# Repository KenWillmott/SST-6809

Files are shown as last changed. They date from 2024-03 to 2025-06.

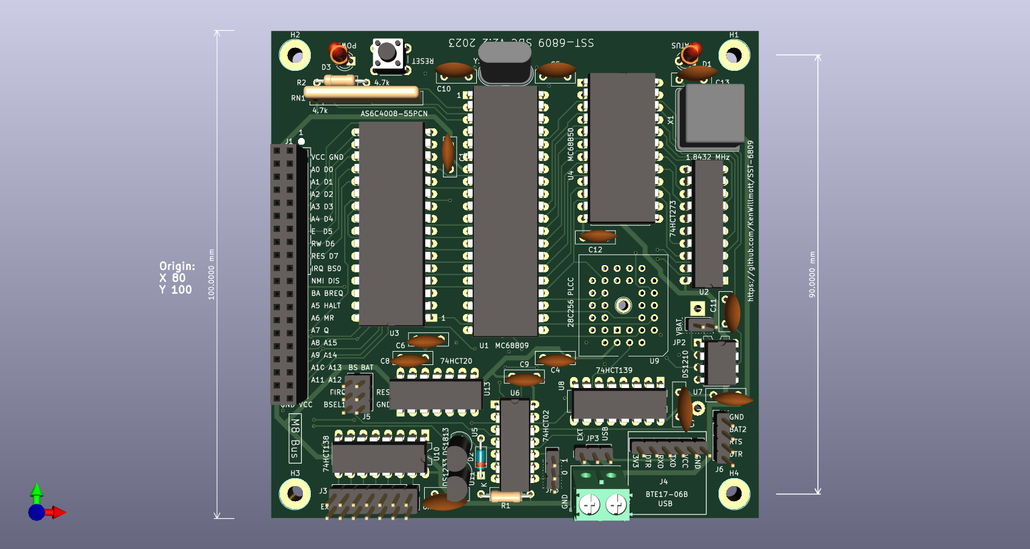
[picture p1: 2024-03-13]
stplus.png

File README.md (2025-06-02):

# SST-6809
MC6809 Single Board Computer

stplus

The SST is a stand alone MC6809 computer. It is inspired by the simple MC6809 SBC designed by Grant Searle:
http://searle.x10host.com/6809/Simple6809.html
and committed to a PCB design by Jeff Tranter:
http://jefftranter.blogspot.com/2019/01/a-6809-single-board-computer.html

It can be seen that what I call the Searle-Tranter design, has the following features:
- minimal ICs employed to make a useful stand alone system
- no PAL, GAL, or other programmable support logic ("glue") IC's, instead only standard 74xx MSI logic parts
- entirely through hole, DIP IC construction consistent with a vintage design. No surface mount components at all

The SST-6809 maintains the same overall approach, while adding some improvements and enhancements. Thus it is a "Super Searle Tranter" or SST. The fundamental features are:
- fairly granular address decoding, using only 4 74xx devices and one address latch for expanded memory
- full featured expansion bus, several expansion boards are already available
- separate UART and CPU clocks, allowing the MCU to run at the maximum 2.0MHz with the same 115200 baud communications
- 512kb NVRAM provides 56kb main and 456kb random access, battery backed up storage
- 32kb EEPROM jumper and software selectable in 4kb pages.
- option to use either USB adapter power, or 5V provided at screw connector terminals

The 10cm x 10cm form factor, including standard connector and mounting locations, create a "family" of boards that can interoperate in different ways. As a very minimal board, the SST does not support all of them, however its connector will support up to about 3 standard peripheral card in the M8 family, such as the M8 game board or the M8 6522/proto board. This can be accomplished using stacking connectors. The same boards may be used as vertically mounted cards on a bus - this configuration is a work in progress, however all the current cards could be used in that configuration instead (with a different connector installed).

The first PCB (V1.0) status was "assembled and testing". The EEPROM fails, a problem with the pin assignments was found.

The second and third PCB, V2.0 and V2.1, were completed. These intermediate versions do work, but V2.0 requires wire jumpers to replace a missing trace.

The current board version, V2.2, is fully operational and has some improvements such as selectable I/O memory address, and socket compatibility of 128/512k NVRAM IC's.

Detailed information can be found at:
https://exileinparadise.com/sst-6809:top
as well as the wiki:
https://github.com/KenWillmott/SST-6809/wiki

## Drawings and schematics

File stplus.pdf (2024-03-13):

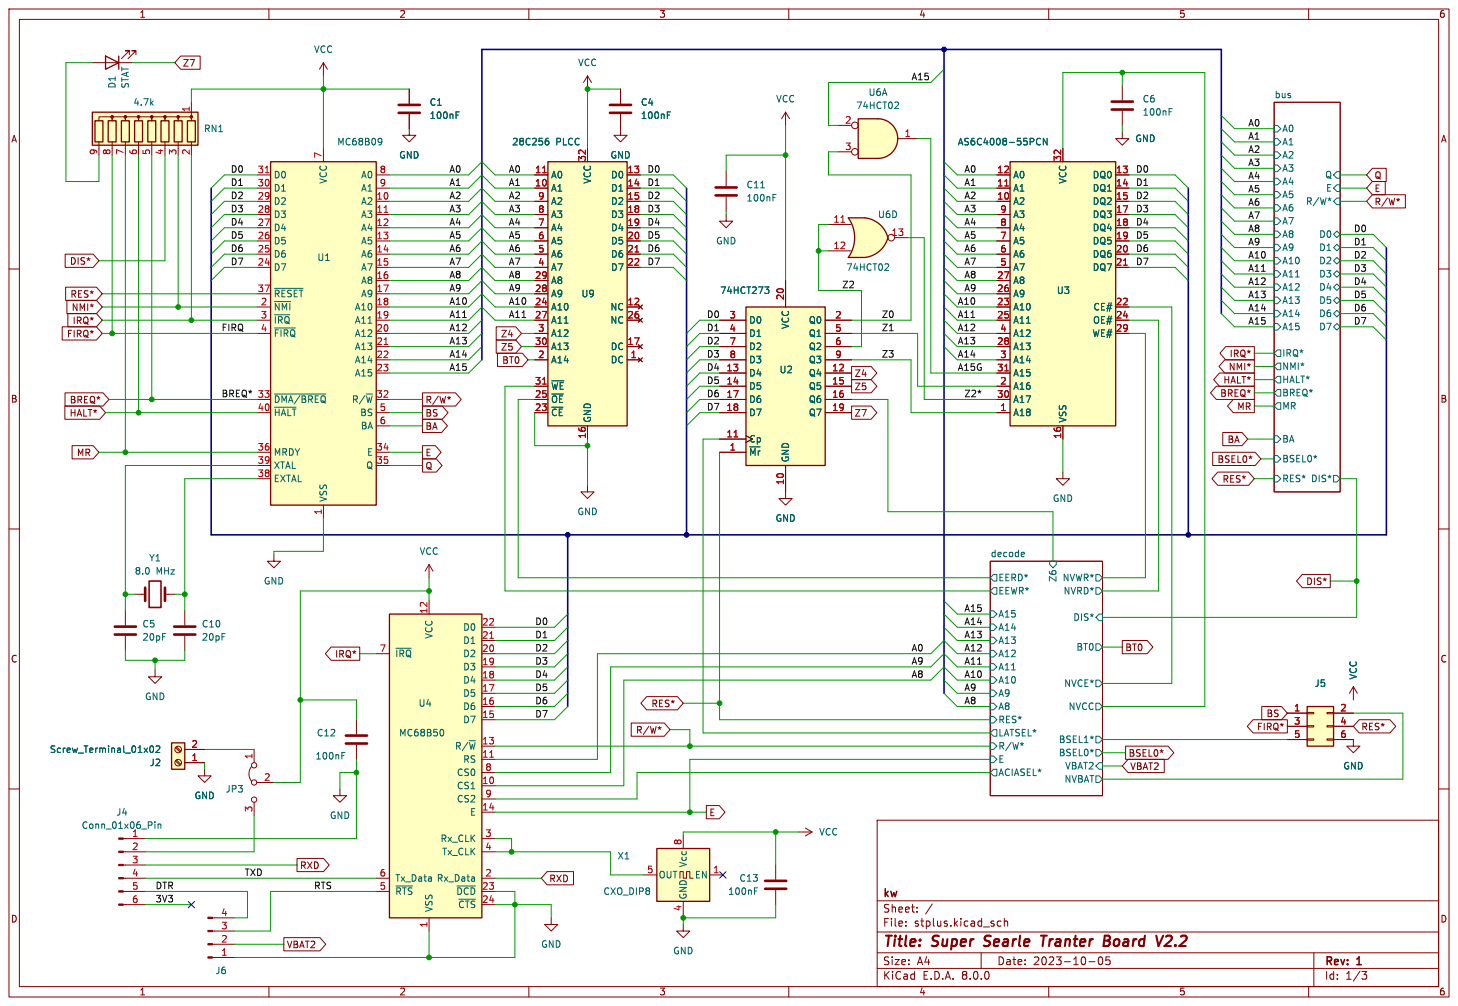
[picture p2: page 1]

1 A2 10 A3 11 A4 12 A5 13 A6 14 A7 15 A8 16 A9 17 A10 18 A11 19 ~{NMI} 2 A12 20 A13 21 A14 22 A15 23 D7 24 D6 25 D5 26 D4 27 D3 28 D2 29 ~{IRQ} 3 D1 30 D0 31 R/~{W}32 ~{DMA/BREQ} 33 E

File: stplus.kicad_sch Sheet: / kw

Id: 1/3 Title: Super Searle Tranter Board V2.2

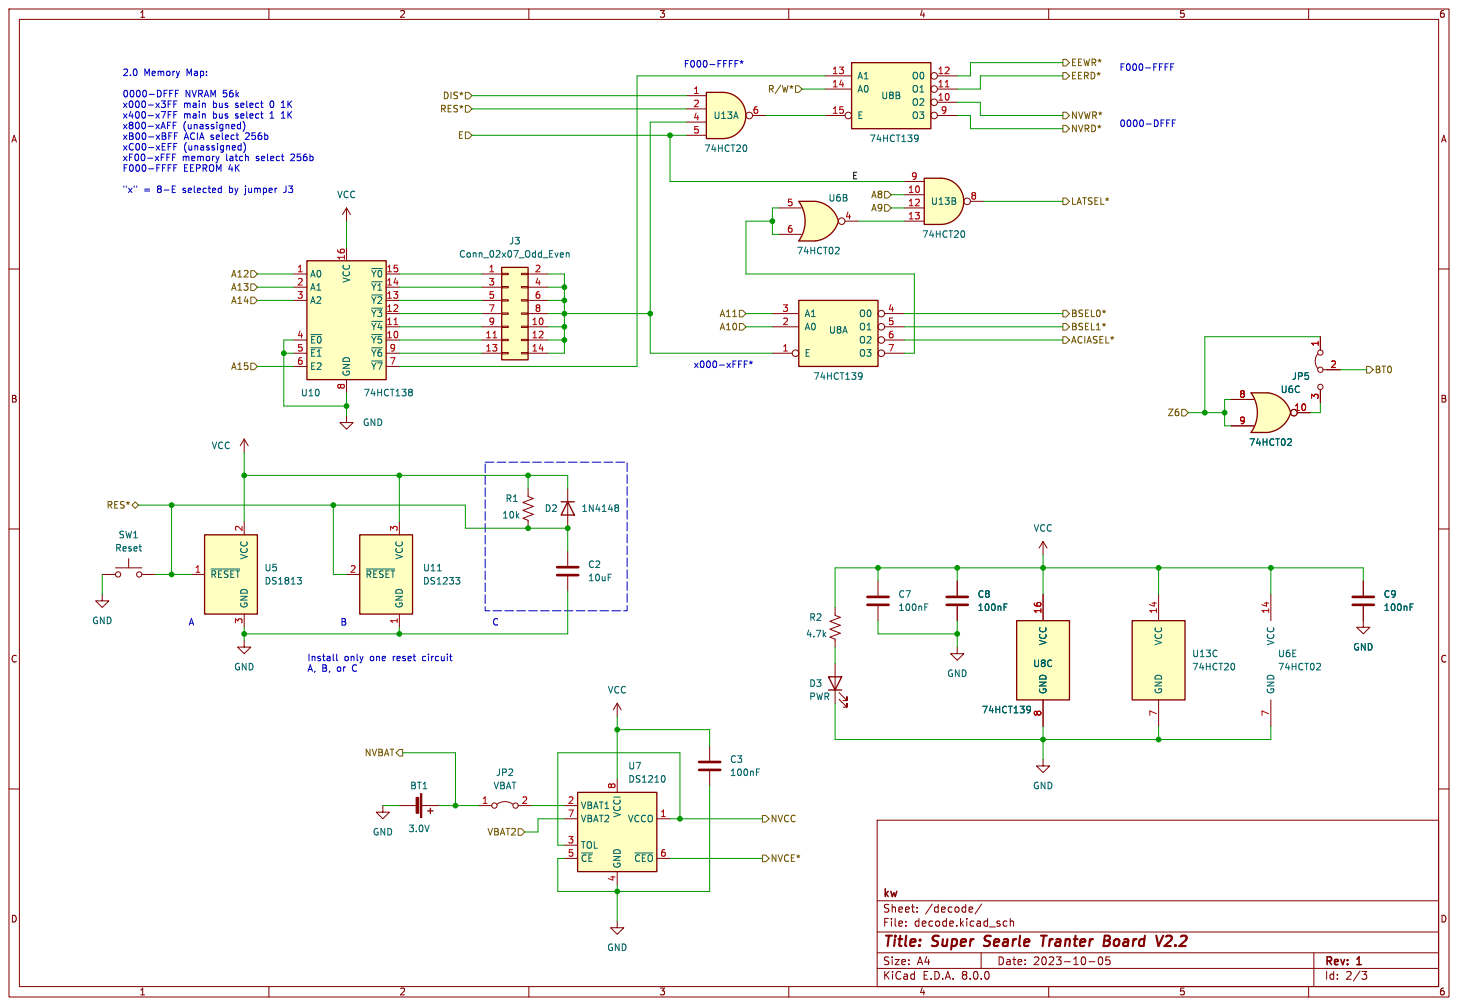
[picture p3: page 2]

LATSEL* EEWR* EERD* NVWR* NVRD* BSEL0* ACIASEL* E

File: decode.kicad_sch Sheet: /decode/ kw

Id: 2/3 Title: Super Searle Tranter Board V2.2

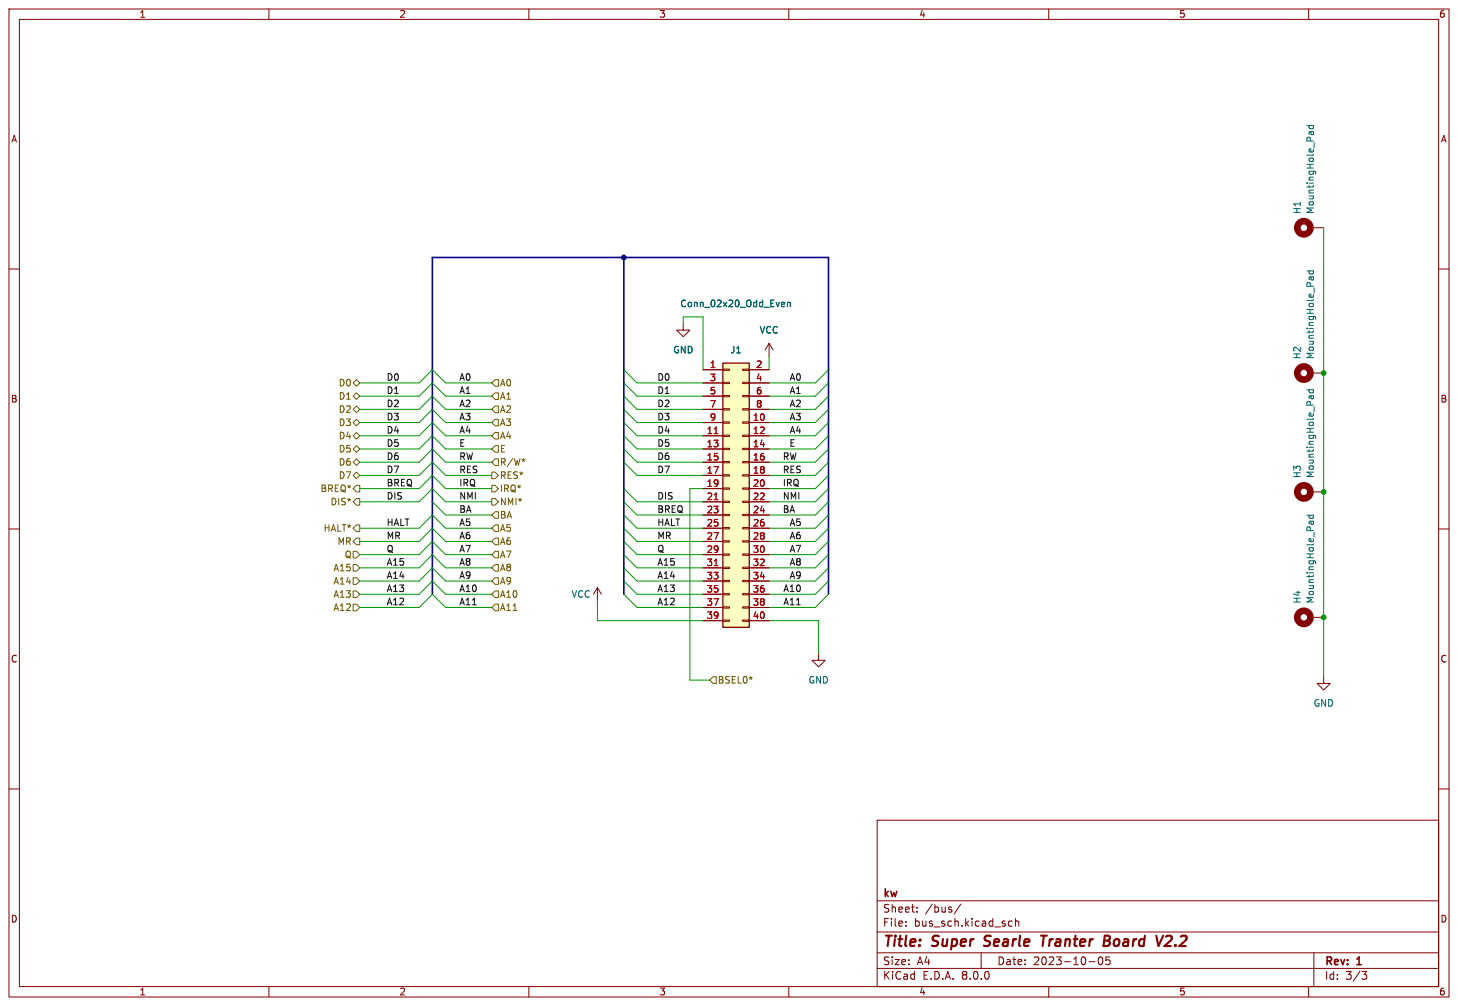
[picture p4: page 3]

File: bus_sch.kicad_sch Sheet: /bus/ kw 1

Id: 3/3 Title: Super Searle Tranter Board V2.2

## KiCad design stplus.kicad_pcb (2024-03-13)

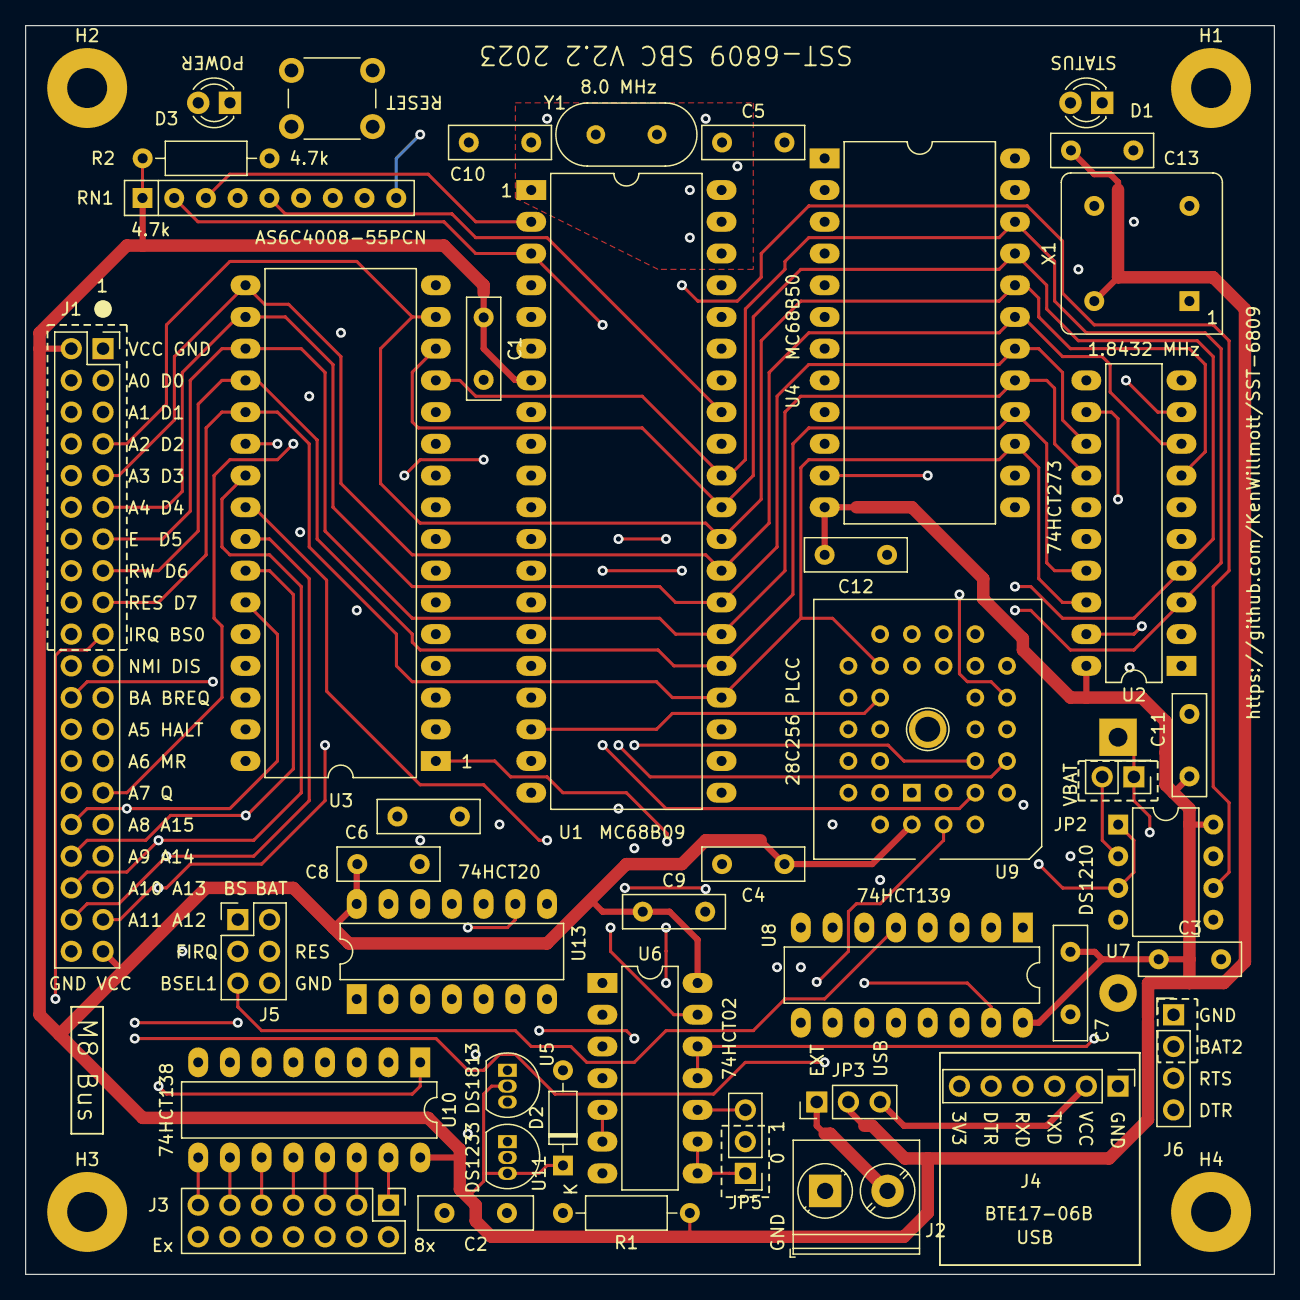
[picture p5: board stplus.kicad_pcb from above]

Board: 4 copper layers, 100.0 x 100.0 mm, 48 parts (1 on the bottom side), 87 nets.

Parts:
BT1: 3.0V; BatteryHolder_Keystone_103_1x20mm
C1, C3, C4, C6, C8, C9, C11, C12, C13: 100nF; C_Disc_D8.0mm_W2.5mm_P5.00mm
C2: 10uF; C_Disc_D9.0mm_W2.5mm_P5.00mm
C5, C10: 20pF; C_Disc_D8.0mm_W2.5mm_P5.00mm
C7: 100nF; C_Disc_D9.0mm_W2.5mm_P5.00mm
D1: STAT; LED_D3.0mm
D2: 1N4148; D_DO-35_SOD27_P7.62mm_Horizontal
D3: PWR; LED_D3.0mm
H1, H2, H3, H4: MountingHole_Pad; MountingHole_3.2mm_M3_Pad
J1: Conn_02x20_Odd_Even; PinSocket_2x20_P2.54mm_Vertical
J2: Screw_Terminal_01x02; TerminalBlock_Phoenix_PT-1,5-2-5.0-H_1x02_P5.00mm_Horizontal
J3: Conn_02x07_Odd_Even; PinHeader_2x07_P2.54mm_Vertical
J4: Conn_01x06_Pin; PinHeader_1x06_P2.54mm_Vertical
J5: Conn_02x03_Odd_Even; PinHeader_2x03_P2.54mm_Vertical
J6: Conn_01x04_Pin; PinHeader_1x04_P2.54mm_Vertical
JP2: VBAT; PinHeader_2x01_P2.54mm_Vertical
JP3, JP5: Jumper_3_Bridged12; PinHeader_1x03_P2.54mm_Vertical
R1: 10k; R_Axial_DIN0207_L6.3mm_D2.5mm_P10.16mm_Horizontal
R2: 4.7k; R_Axial_DIN0207_L6.3mm_D2.5mm_P10.16mm_Horizontal
RN1: 4.7k; R_Array_SIP9
SW1: Reset; SW_PUSH_6mm_H5mm
U1: MC68B09; DIP-40_W15.24mm_LongPads
U2: 74HCT273; DIP-20_W7.62mm_LongPads
U3: AS6C4008-55PCN; DIP-32_W15.24mm_LongPads
U4: MC68B50; DIP-24_W15.24mm_LongPads
U5: DS1813; TO-92L_Inline
U6: 74HCT02; DIP-14_W7.62mm_LongPads
U7: DS1210; DIP-8_W7.62mm
U8: 74HCT139; DIP-16_W7.62mm_LongPads
U9: 28C256 PLCC; PLCC-32_THT-Socket
U10: 74HCT138; DIP-16_W7.62mm_LongPads
U11: DS1233; TO-92L_Inline
U13: 74HCT20; DIP-14_W7.62mm_LongPads
X1: CXO_DIP8; Oscillator_DIP-8
Y1: 8.0 MHz; Crystal_HC18-U_Vertical

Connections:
/A0: J1.4, U1.8 (A0), U3.12 (A0), U4.11 (RS), U9.11 (A0)
/A1: J1.6, U1.9 (A1), U3.11 (A1), U9.10 (A1)
/A2: J1.8, U1.10 (A2), U3.10 (A2), U9.9 (A2)
/A3: J1.10, U1.11 (A3), U3.9 (A3), U9.8 (A3)
/A4: J1.12, U1.12 (A4), U3.8 (A4), U9.7 (A4)
/A5: J1.26, U1.13 (A5), U3.7 (A5), U9.6 (A5)
/A6: J1.28, U1.14 (A6), U3.6 (A6), U9.5 (A6)
/A7: J1.30, U1.15 (A7), U3.5 (A7), U9.4 (A7)
/A8: J1.32, U1.16 (A8), U3.27 (A8), U4.10 (CS1), U9.29 (A8), U13.10
/A9: J1.34, U1.17 (A9), U3.26 (A9), U4.8 (CS0), U9.28 (A9), U13.12
/A10: J1.36, U1.18 (A10), U3.23 (A10), U8.2 (A0), U9.24 (A10)
/A11: J1.38, U1.19 (A11), U3.25 (A11), U8.3 (A1), U9.27 (A11)
/A12: J1.37, U1.20 (A12), U3.4 (A12), U10.1 (A0)
/A13: J1.35, U1.21 (A13), U3.28 (A13), U10.2 (A1)
/A14: J1.33, U1.22 (A14), U3.3 (A14), U10.3 (A2)
/A15: J1.31, U1.23 (A15), U6.2, U10.6 (E2)
/A15G: U3.31 (A15), U6.1
/D0: J1.3, U1.31 (D0), U2.3 (D0), U3.13 (DQ0), U4.22 (D0), U9.13 (D0)
/D1: J1.5, U1.30 (D1), U2.4 (D1), U3.14 (DQ1), U4.21 (D1), U9.14 (D1)
/D2: J1.7, U1.29 (D2), U2.7 (D2), U3.15 (DQ2), U4.20 (D2), U9.15 (D2)
/D3: J1.9, U1.28 (D3), U2.8 (D3), U3.17 (DQ3), U4.19 (D3), U9.18 (D3)
/D4: J1.11, U1.27 (D4), U2.13 (D4), U3.18 (DQ4), U4.18 (D4), U9.19 (D4)
/D5: J1.13, U1.26 (D5), U2.14 (D5), U3.19 (DQ5), U4.17 (D5), U9.20 (D5)
/D6: J1.15, U1.25 (D6), U2.17 (D6), U3.20 (DQ6), U4.16 (D6), U9.21 (D6)
/D7: J1.17, U1.24 (D7), U2.18 (D7), U3.21 (DQ7), U4.15 (D7), U9.22 (D7)
/DTR: J4.5, J6.4
/RTS: J6.3, U4.5 (~RTS)
/TXD: J4.4, U4.6 (Tx_Data)
/Z0: U2.2 (Q0), U6.3
/Z1: U2.5 (Q1), U3.2 (A16)
/Z2: U2.6 (Q2), U6.11, U6.12
/Z2*: U3.30 (A17), U6.13
/Z3: U2.9 (Q3), U3.1 (A18)
/decode/ACIASEL*: U4.9 (CS2), U8.6 (O2)
/decode/BSEL1*: J5.5, U8.5 (O1)
/decode/EERD*: U8.11 (O1), U9.25 (~OE)
/decode/EEWR*: U8.12 (O0), U9.31 (~WE)
/decode/LATSEL*: U2.11 (Cp), U13.8
/decode/NVBAT: BT1.1 (+), J5.2, JP2.1 (A)
/decode/NVCC: C6.1, U3.32 (VCC), U7.1 (VCCO), U7.3 (TOL)
/decode/NVCE*: U3.22 (CE#), U7.6 (~CEO)
/decode/NVRD*: U3.24 (OE#), U8.9 (O3)
/decode/NVWR*: U3.29 (WE#), U8.10 (O2)
/decode/Z6: JP5.1 (A), U2.16 (Q6), U6.8, U6.9
BA: J1.24, U1.6 (BA)
BREQ*: J1.23, RN1.5 (R4), U1.33 (~DMA/BREQ)
BS: J5.1, U1.5 (BS)
BSEL0*: J1.19, U8.4 (O0)
BT0: JP5.2 (C), U9.2 (A14)
DIS*: J1.21, RN1.4 (R3), U13.1
E: J1.14, U1.34 (E), U4.14 (E), U13.5, U13.9
FIRQ*: J5.3, RN1.8 (R7), U1.4 (~FIRQ)
GND: BT1.2 (-), C1.2, C2.2, C3.2, C4.2, C5.2, C6.2, C7.2, C8.2, C9.2, C10.2, C11.2, C12.2, C13.1, D3.1 (K), H1.1, H2.1, H3.1, H4.1, J1.1, J1.40, J2.1, J4.1, J5.6, J6.1, SW1.2, U1.1 (VSS), U2.10 (GND), U3.16 (VSS), U4.1 (VSS), U4.23 (~DCD), U4.24 (~CTS), U5.3 (GND), U6.7 (GND), U7.4 (GND), U7.5 (~CE), U8.8 (GND), U9.16 (GND), U9.23 (~CE), U10.4 (~E0), U10.5 (~E1), U10.8 (GND), U11.1 (GND), U13.7 (GND), X1.4 (GND)
HALT*: J1.25, RN1.6 (R5), U1.40 (~HALT)
IRQ*: J1.20, RN1.2 (R1), U1.3 (~IRQ), U4.7 (~IRQ)
MR: J1.27, RN1.7 (R6), U1.36 (MRDY)
NMI*: J1.22, RN1.3 (R2), U1.2 (~NMI)
unnamed: D1.2 (A), RN1.9 (R8)
unnamed: D3.2 (A), R2.2
unnamed: J2.2, JP3.1 (A)
unnamed: J3.1, U10.15 (~Y0)
unnamed: J3.3, U10.14 (~Y1)
unnamed: J3.5, U10.13 (~Y2)
unnamed: J3.7, U10.12 (~Y3)
unnamed: J3.9, U10.11 (~Y4)
unnamed: J3.2, J3.4, J3.6, J3.8, J3.10, J3.12, J3.14, U8.1 (E), U13.4
unnamed: J3.11, U10.10 (~Y5)
unnamed: J3.13, U10.9 (~Y6)
unnamed: J4.2, JP3.3 (B)
unnamed: JP2.2 (B), U7.2 (VBAT1)
unnamed: JP5.3 (B), U6.10
unnamed: C10.1, U1.38 (EXTAL), Y1.2
unnamed: C5.1, U1.39 (XTAL), Y1.1
unnamed: U4.3 (Rx_CLK), U4.4 (Tx_CLK), X1.5 (OUT)
unnamed: U6.5, U6.6, U8.7 (O3)
unnamed: U8.15 (E), U13.6
unnamed: U8.13 (A1), U10.7 (~Y7)
unnamed: U6.4, U13.13
Q: J1.29, U1.35 (Q)
RES*: C2.1, D2.2 (A), J1.18, J5.4, R1.2, SW1.1, U1.37 (~RESET), U2.1 (~Mr), U5.1 (~RESET), U11.2 (~RESET), U13.2
RXD: J4.3, U4.2 (Rx_Data)
R/W*: J1.16, U1.32 (R/~W), U4.13 (R/~W), U8.14 (A0)
VBAT2: J6.2, U7.7 (VBAT2)
VCC: C1.1, C3.1, C4.1, C7.1, C8.1, C9.1, C11.1, C12.1, C13.2, D2.1 (K), J1.2, J1.39, JP3.2 (C), R1.1, R2.1, RN1.1 (common), U1.7 (VCC), U2.20 (VCC), U4.12 (VCC), U5.2 (VCC), U6.14 (VCC), U7.8 (VCCI), U8.16 (VCC), U9.32 (VCC), U10.16 (VCC), U11.3 (VCC), U13.14 (VCC), X1.8 (Vcc)
Z4: U2.12 (Q4), U9.3 (A12)
Z5: U2.15 (Q5), U9.30 (A13)
Z7: D1.1 (K), U2.19 (Q7)

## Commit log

2023-10-08 beta schematic
2023-10-08 beta board image
2023-10-10 latest schematic
